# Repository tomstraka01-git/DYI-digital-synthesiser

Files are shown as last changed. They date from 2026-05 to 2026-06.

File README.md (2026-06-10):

# DYI digital synthesiser
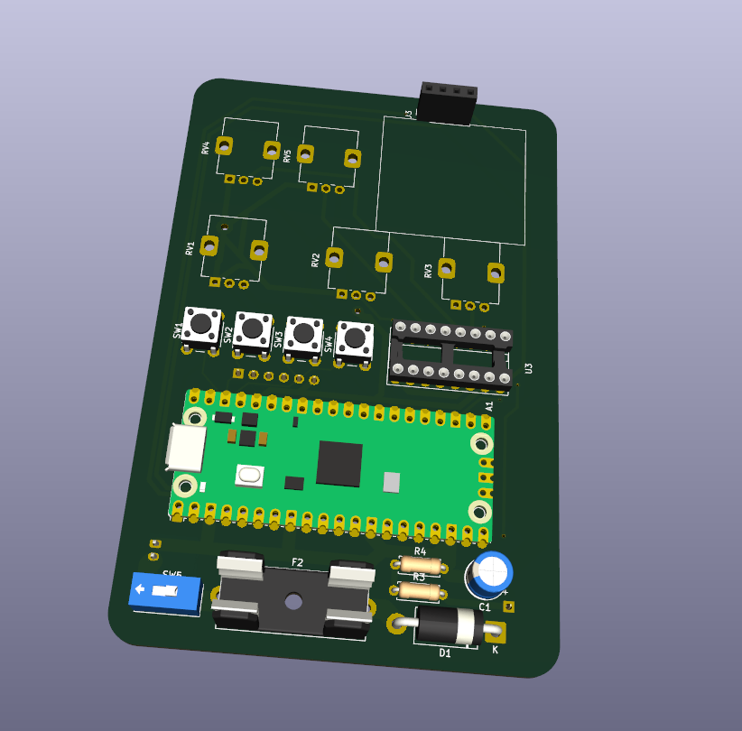
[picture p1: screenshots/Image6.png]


## What is it?
It is a digital synthesizer fully made by me. It has 4 buttons and 5 controllable analog knobs to change settings. It can produce polyphonic sound and can connect to midi. It has settings like frequency, detune, volume, filters, chorus, delay, lfo, etc. It has two 2 watt speakers to produce sound and fully made by me pcb.

## Why?
I have always liked music, since i was kid i played piano, so i wanted to connect my interest in electronics and music into one project. That is why i  made this synthesizer. It has taught me about digital sound and audio alot.

## Electronics
The project uses custom pcb and some modules. It uses PCM5102 I2S audio module for sound generation and PAM8403 for sound amplifying, before it goes into 2040 8 ohm 2 watt speakers. It uses pico 2 as a microcontroller that does all the calculations etc. The pcb is going to be made by jlcpcb and it is fully opensource. It uses voltage dividers for battery percent readings, diode and a fast fuse for safety protection.

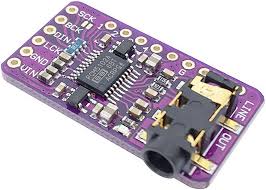
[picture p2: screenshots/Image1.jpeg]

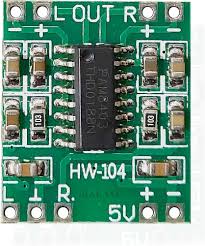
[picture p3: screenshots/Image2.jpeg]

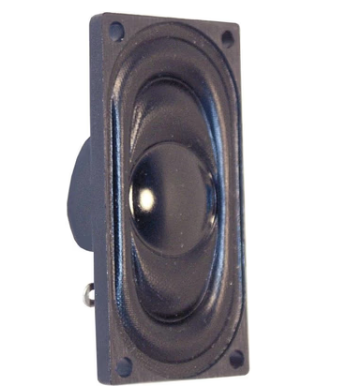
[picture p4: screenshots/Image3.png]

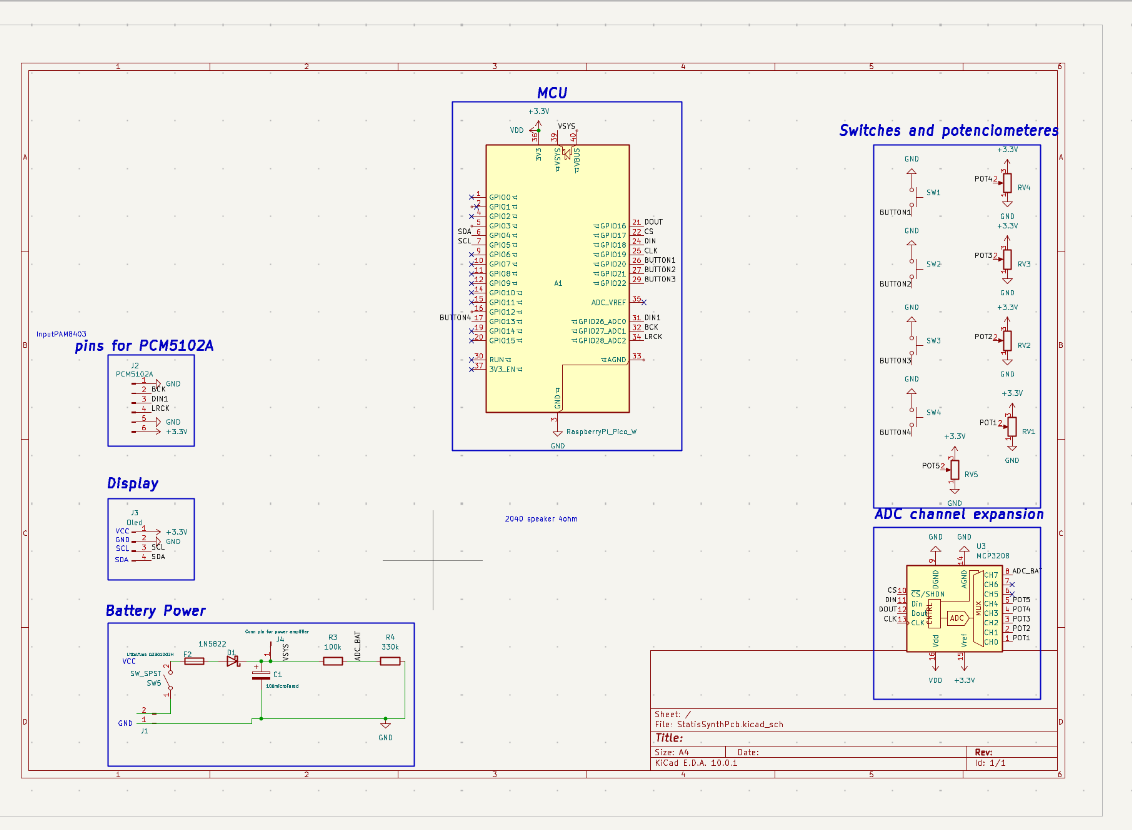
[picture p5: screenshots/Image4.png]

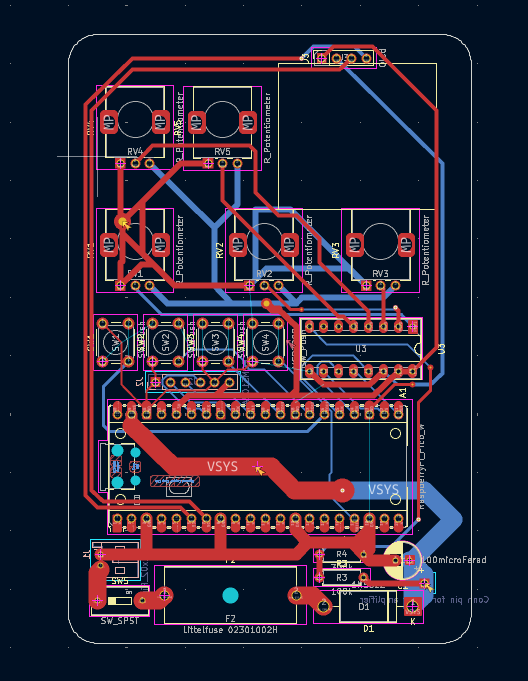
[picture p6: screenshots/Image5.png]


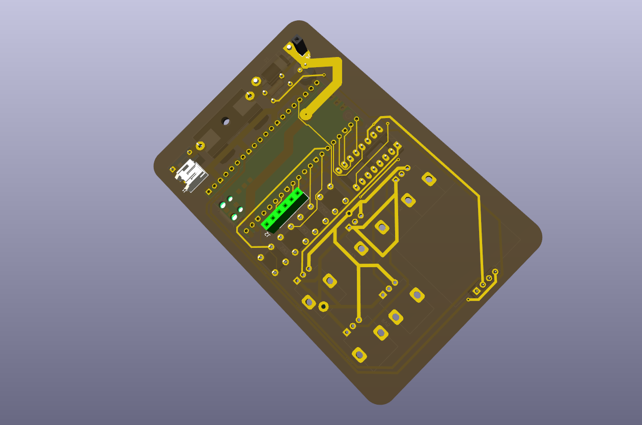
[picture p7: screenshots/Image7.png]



## Case
I wont use a case for the synthesizer, it will all be on the pcb and few things wich are not on it, like battery are gonna be held there with zip ties and other things.


| Name | Purpose | Quantity | Total Cost (USD) | Link | Distributor |
|:---|:---|---:|---:|:---|:---|
| Custom JLCPCB PCB | A custom pcb connecting parts together. | 1 | 6.9 | https://cart.jlcpcb.com/quote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 | JLCPCB |
| Raspberry Pi Pico W | Microcontroller, the brain of the synthesizer. | 1 | 11.0 | https://www.laskakit.cz/raspberry-pi-pico-w/ | laskakit.cz |
| 2040 speaker 2 watt 8 ohm | Speaker for producing audio. | 2 | 1.06 | https://www.lcsc.com/product-detail/C50387229.html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 | lcsc |
| GY-PCM5102 I2S audio module | Audio generator, wich then passes audio to the amplifier | 1 | 4.71 | https://www.laskakit.cz/gy-pcm5102-i2s-audio-modul/ | laskakit.cz |
| DuPont pins Female 40pin | Female dupont pins for pico 2. | 1 | 0.34 | https://dratek.cz/arduino-platforma/913-dupont-dutinkova-lista-samice-samec.html | Dratek.cz |
| Diode 1N5822 | Diode for reverse battery protection. 10 is minimum quantity. | 5 | 1.19 | https://www.lcsc.com/product-detail/schottky-diodes_stmicroelectronics-1n5822_C915962.html | lcsc |
| Button, 6 x 6 x 6 mm | Button for changing things in menu. | 4 | 0.39 | https://dratek.cz/arduino-platforma/1253-mikrospinac-6x6x6-mm-tlacitko.html | Dratek.cz |
| 5 $\times$ 20 GLASS QUICK BLOW FUSE 3A | Fast blow fuse for safety in the pcb. | 10 | 0.59 | https://www.lcsc.com/product-detail/Glass-Fuses_3A-250VAC_C3118.html | lcsc |
| 5 $\times$ 20mm fuse holder, PCB THT | Fuse holder. Holds the fuse, 20 is the minimum quantity. | 5 | 0.4 | https://www.lcsc.com/product-detail/C3131.html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 | lcsc |
| Metalized rezistor 100K - 0,25W 1% | Resistor for voltage divider. | 2 | 0.1 | https://dratek.cz/arduino-platforma/7653-rezistor-100k-0.25-w-1.html | Dratek.cz |
| Metalized rezistor 330K - 0,25W 1% | Resistor for voltage divider. | 4 | 0.19 | https://dratek.cz/arduino-platforma/174965-metalizovany-rezistor-330k-0-25w-1.html | Dratek.cz |
| Condensator  50v 100microfarad | Condensator for power smoothing. | 4 | 0.19 | https://dratek.cz/arduino-platforma/7825-kondenzator-100uf-50v.html | Dratek.cz |
| POT 10k$\Omega$ Through Hole | Potenciometer for the knobs in the synthesizer. Used to control value and settings. | 10 | 6.92 | https://www.lcsc.com/product-detail/C209779.html?s_z=n_q_C209779&globalKeyword=C209779 | lcsc |
| JST S2B-PH-K-S | The jst pin for battery. 20 is the minimum quantity | 20 | 0.76 | https://www.lcsc.com/product-detail/Wire-To-Board-Wire-To-Wire-Connector_JST-S2B-PH-K-S-LF-SN_C173752.html | lcsc |
| MICROCHIP MCP3208-CI/P | analog multiplexer to read potencimeters, because pico does not have enough adc pins | 1 | 4.27 | https://www.lcsc.com/product-detail/C1543277.html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 | lcsc |
| 2.54mm 16P DIP Tin Square Hole 7.62mm DIP-16 IC Sockets RoHS | Holder for the MCP3208 chip. 10 is the minimum quantity on lcsc. | 10 | 0.48 | https://www.lcsc.com/product-detail/IC-Sockets_BOOMELE-Boom-Precision-Elec-C2326_C2326.html | lcsc |
| Digital audio amplifier PAM8403 - 2 x 3W | To amplify the sound generated by the PCM5102A for speakers | 1 | 0.67 | https://dratek.cz/arduino-platforma/953-audio-zesilovac-2x3w.html | Dratek.cz |
| IIC I2C OLED displej 1,3" - White, 128 x 64 | Oled display for vizualization of the sound and values. Allows the user to see what vaues he is setting and what mode is he on. | 1 | 8.01 | https://dratek.cz/arduino-platforma/3181-iic-i2c-oled-1-3-displej-128x64-bily.html | Dratek.cz |

Total shipping: $34

Total price: $86

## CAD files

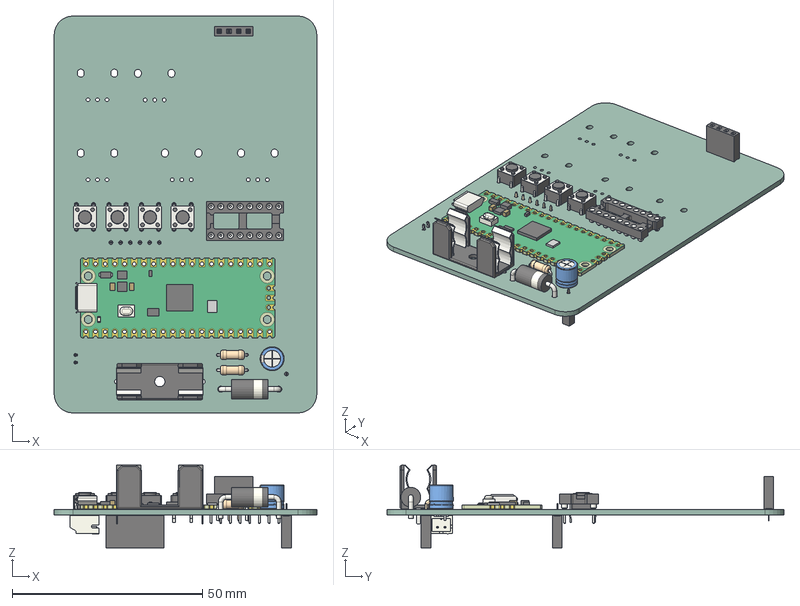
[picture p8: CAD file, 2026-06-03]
Synthesizer.step
69.0 x 104.2 x 21.7 mm
PinSocket_1x04_P2.54mm_Vertical
DIP-16_W7.62mm_Socket
CP_Radial_D6.3mm_P2.50mm
SW_PUSH_6mm x 4
R_Axial_DIN0207_L6.3mm_D2.5mm_P7.62mm_Horizontal x 2
RaspberryPi_Pico
D_DO-201AD_P15.24mm_Horizontal
Fuseholder_Cylinder-5x20mm_Schurter_0031_8201_Horizontal_Open
PinSocket_1x01_P2.54mm_Vertical
JST_PH_S2B-PH-K_1x02_P2.00mm_Horizontal
PinSocket_1x06_P2.54mm_Vertical
StatisSynthPcb_PCB

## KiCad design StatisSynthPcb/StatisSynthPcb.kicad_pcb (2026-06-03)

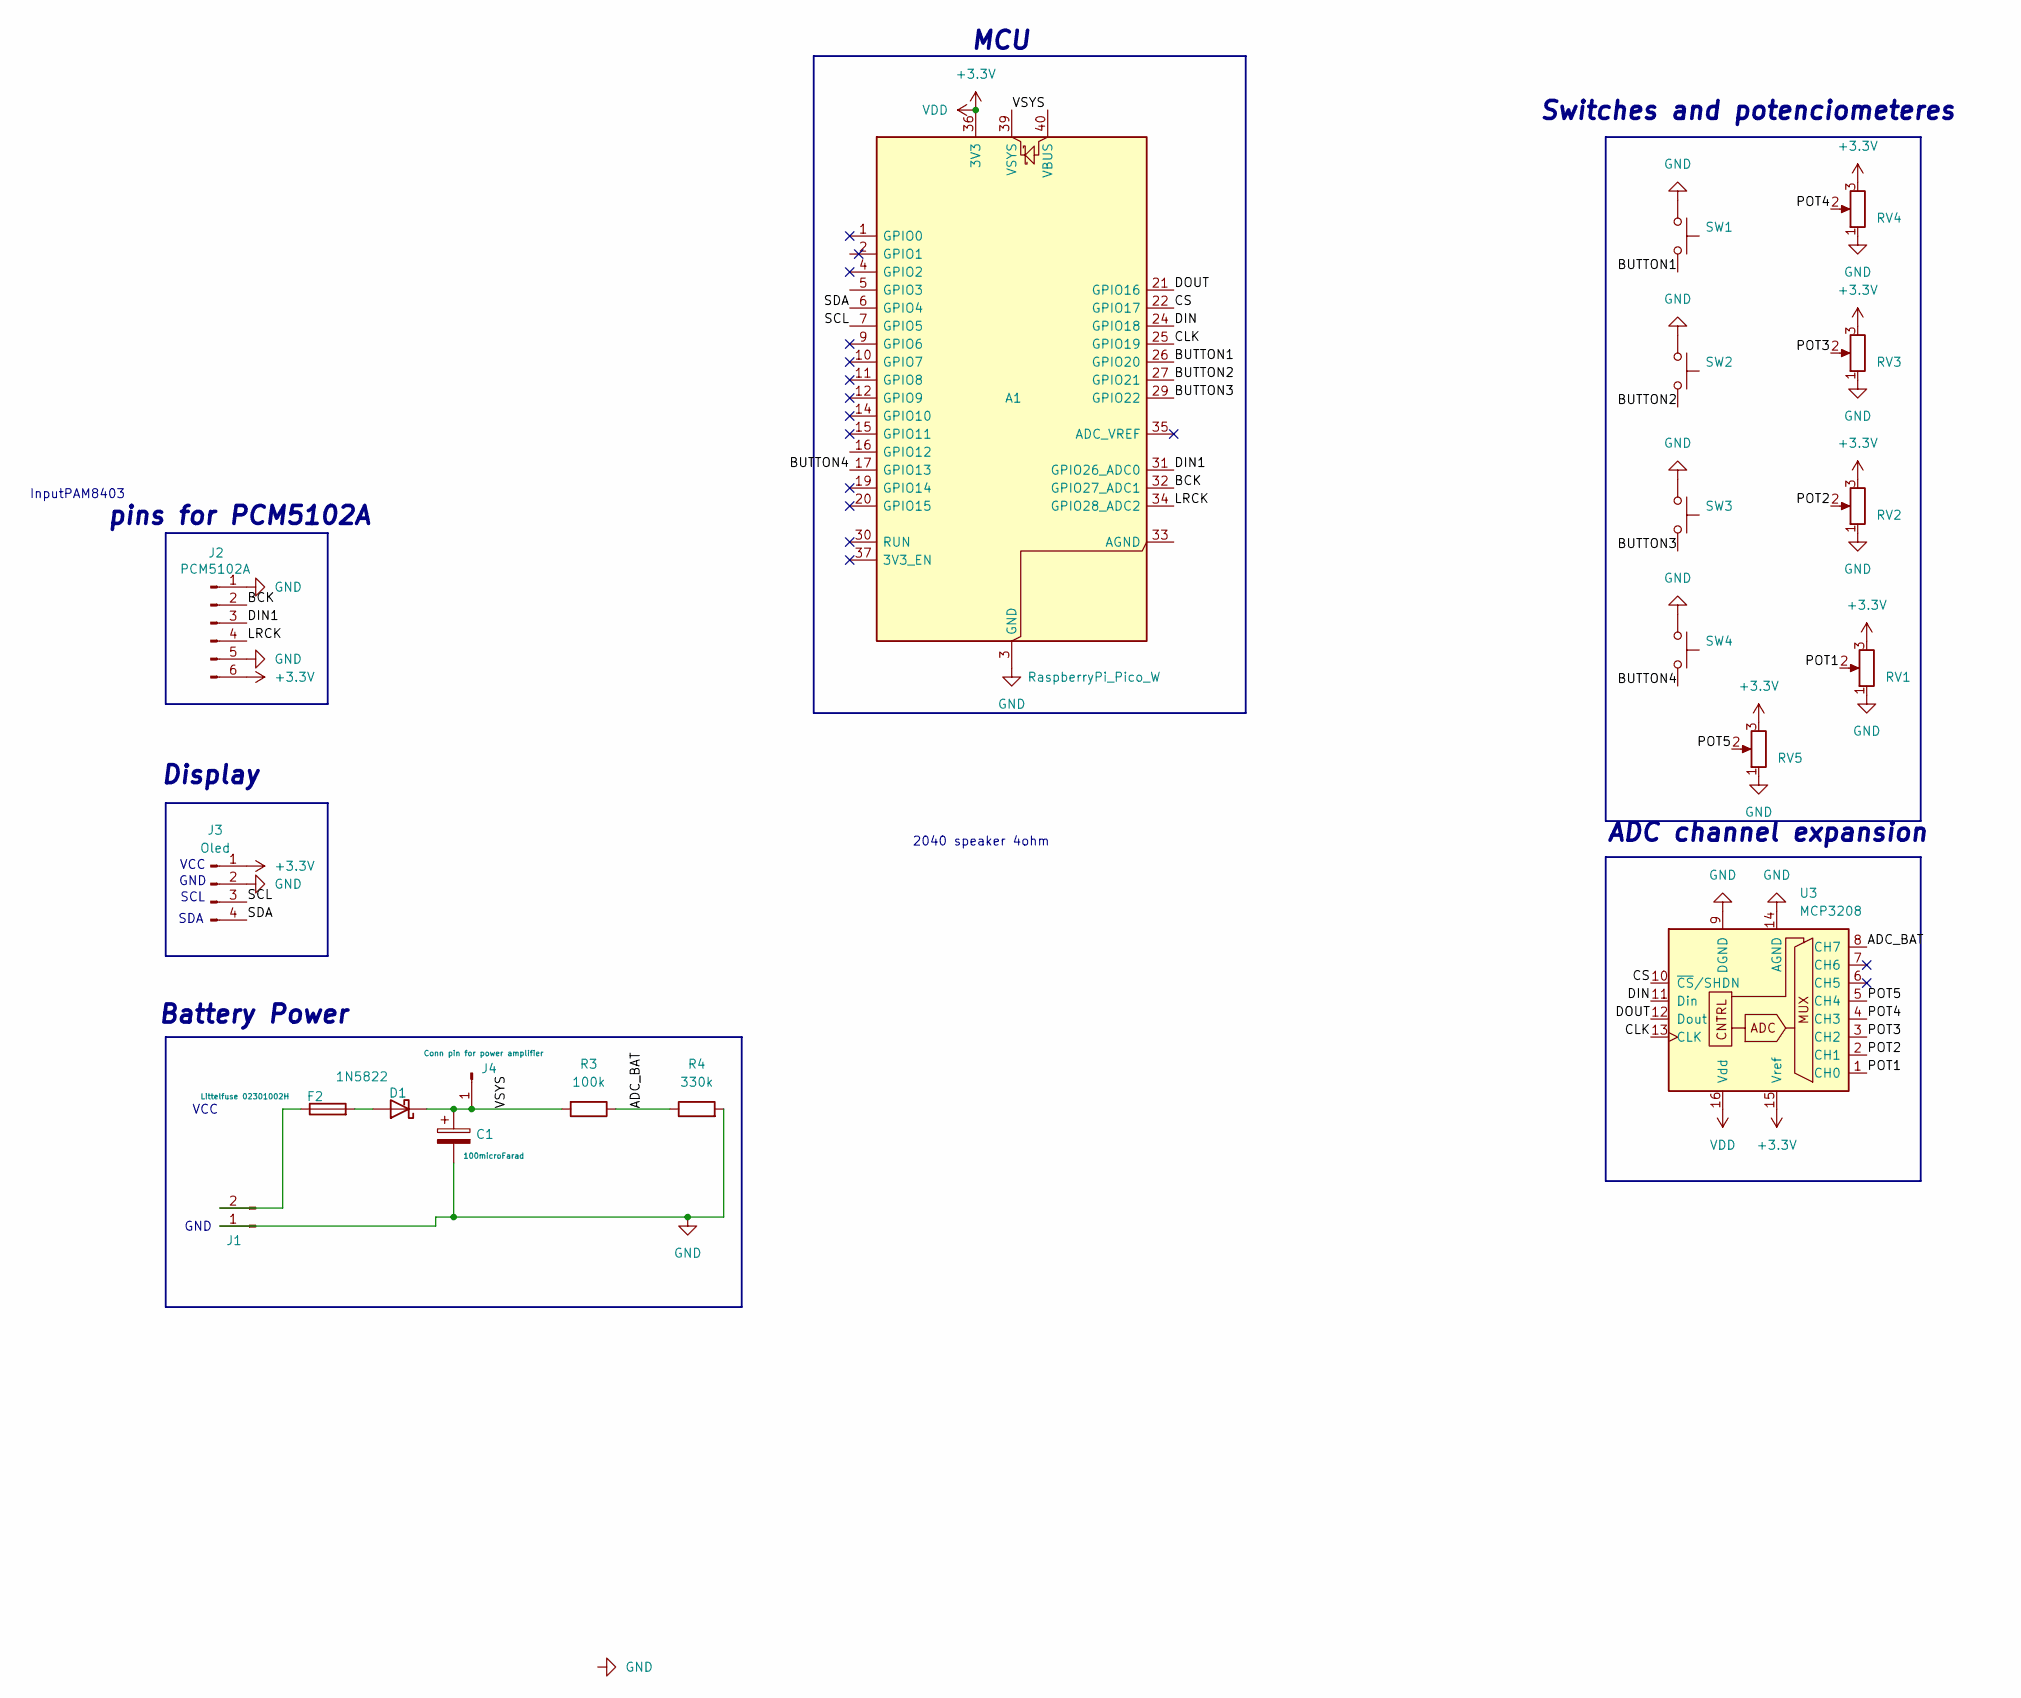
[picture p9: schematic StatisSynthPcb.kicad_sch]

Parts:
A1: RaspberryPi_Pico_W; RaspberryPi_Pico_Common
C1: 100microFarad; CP_Radial_D6.3mm_P2.50mm
D1: 1N5822; D_DO-201AD_P15.24mm_Horizontal
F2: Littelfuse 02301002H; Fuseholder_Cylinder-5x20mm_Schurter_0031_8201_Horizontal_Op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
J1: Conn_01x02_Pin; JST_PH_S2B-PH-K_1x02_P2.00mm_Horizontal
J2: PCM5102A; PinSocket_1x06_P2.54mm_Vertical
J3: Oled; PinSocket_1x04_P2.54mm_Vertical
J4: Conn pin for power amplifier; PinSocket_1x01_P2.54mm_Vertical
R3: 100k; R_Axial_DIN0207_L6.3mm_D2.5mm_P7.62mm_Horizontal
R4: 330k; R_Axial_DIN0207_L6.3mm_D2.5mm_P7.62mm_Horizontal
RV1, RV2, RV3, RV4, RV5: R_Potentiometer; Potentiometer_Alps_RK09K_Single_Vertical
SW1, SW2, SW3, SW4: SW_Push; SW_PUSH_6mm
U3: MCP3208; DIP-16_W7.62mm_Socket_LongPads

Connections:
+3.3V: A1.36 (3V3), J2.6, J3.1, RV1.3, RV2.3, RV3.3, RV4.3, RV5.3, U3.15 (Vref), U3.16 (Vdd)
/ADC_BAT: R3.1, R4.1, U3.8 (CH7)
/BCK: A1.32 (GPIO27_ADC1), J2.2
/BUTTON1: A1.26 (GPIO20), SW1.2
/BUTTON2: A1.27 (GPIO21), SW2.2
/BUTTON3: A1.29 (GPIO22), SW3.2
/BUTTON4: A1.17 (GPIO13), SW4.2
/CLK: A1.25 (GPIO19), U3.13 (CLK)
/CS: A1.22 (GPIO17), U3.10 (~CS/SHDN)
/DIN: A1.24 (GPIO18), U3.11 (Din)
/DIN1: A1.31 (GPIO26_ADC0), J2.3
/DOUT: A1.21 (GPIO16), U3.12 (Dout)
/LRCK: A1.34 (GPIO28_ADC2), J2.4
/POT1: RV1.2, U3.1 (CH0)
/POT2: RV2.2, U3.2 (CH1)
/POT3: RV3.2, U3.3 (CH2)
/POT4: RV4.2, U3.4 (CH3)
/POT5: RV5.2, U3.5 (CH4)
/SCL: A1.7 (GPIO5), J3.3
/SDA: A1.6 (GPIO4), J3.4
/VSYS: A1.39 (VSYS), C1.1, D1.1 (K), J4.1 (Pin_1_1), R3.2
GND: A1.3 (GND), A1.8 (GND), A1.13 (GND), A1.18 (GND), A1.23 (GND), A1.28 (GND), A1.38 (GND), C1.2, J1.1, J2.1, J2.5, J3.2, R4.2, RV1.1, RV2.1, RV3.1, RV4.1, RV5.1, SW1.1, SW2.1, SW3.1, SW4.1, U3.9 (DGND), U3.14 (AGND)
unnamed: D1.2 (A), F2.2
unnamed: F2.1, J1.2

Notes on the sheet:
Battery Power
ADC channel expansion
SCL
VCC
InputPAM8403
GND
pins for PCM5102A
SDA
Switches and potenciometeres
GND
Display
2040 speaker 4ohm
MCU

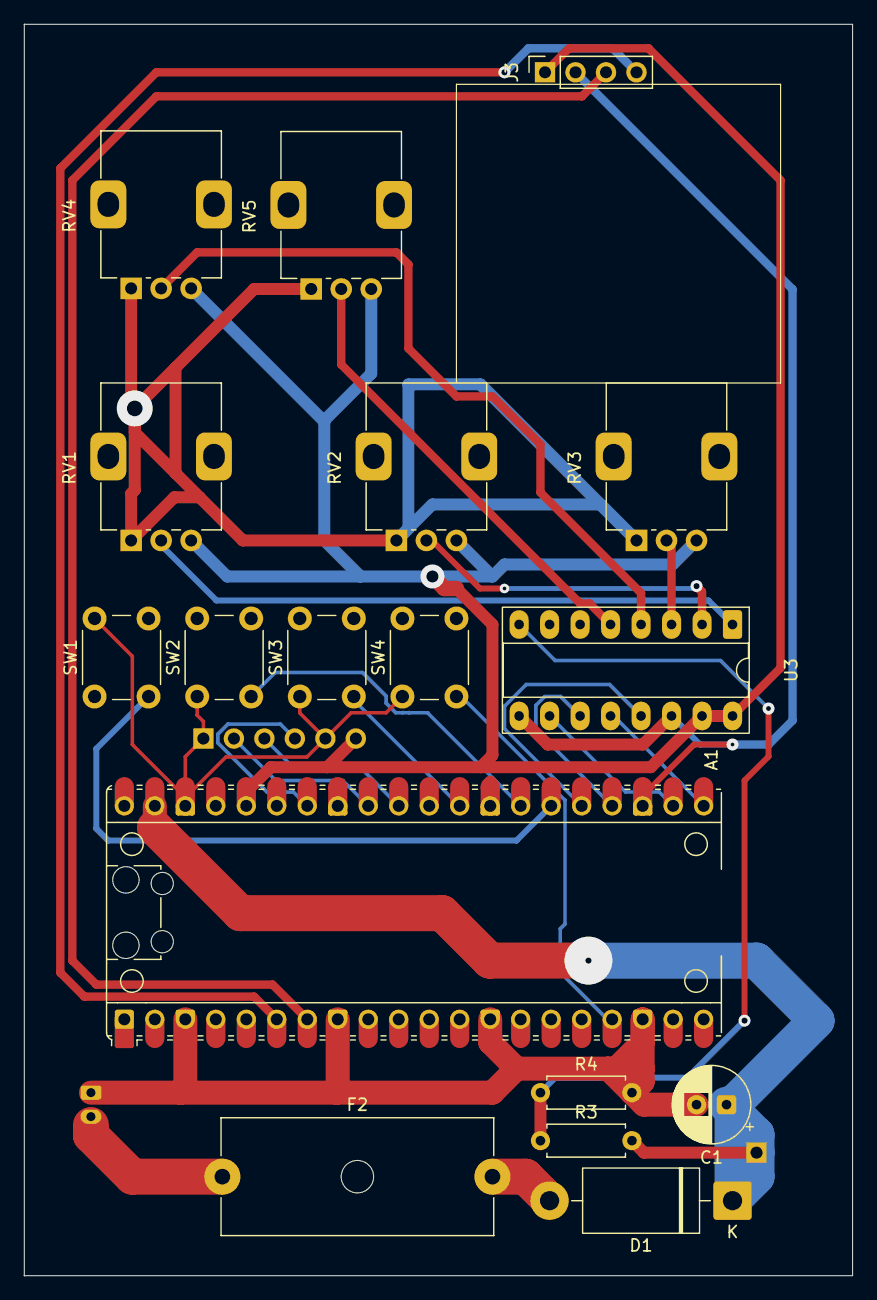
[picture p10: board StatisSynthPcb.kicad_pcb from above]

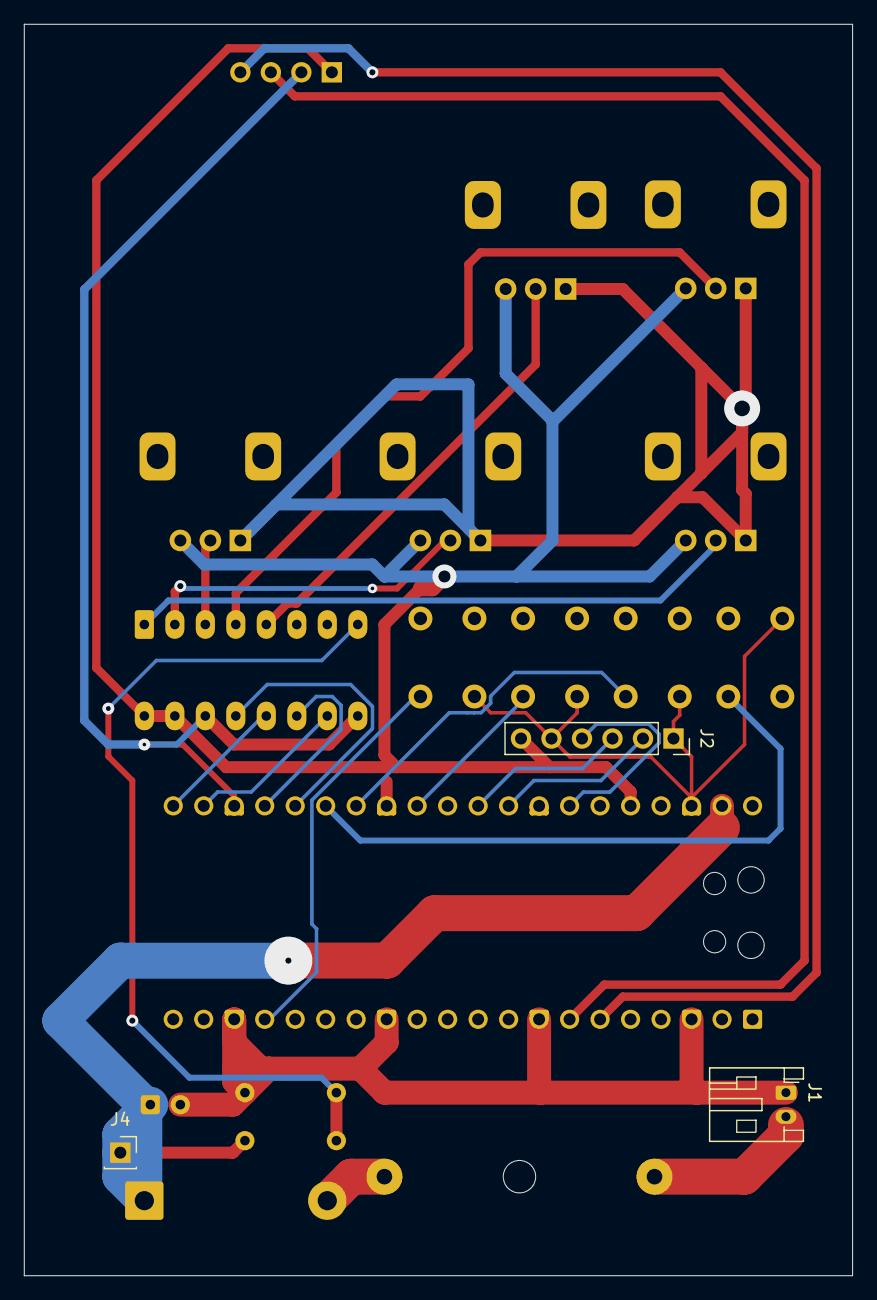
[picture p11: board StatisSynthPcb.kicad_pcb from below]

Board: 2 copper layers, 69.0 x 104.2 mm, 20 parts (3 on the bottom side), 24 nets.

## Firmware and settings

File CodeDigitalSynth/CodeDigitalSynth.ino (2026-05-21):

#include <I2S.h>
#include <SPI.h>
#include "MCP_ADC.h"
#include <Adafruit_TinyUSB.h>
#include <MIDI.h>
#include "pico/multicore.h"

#include <Adafruit_GFX.h>
#include <Adafruit_SSD1306.h>
#include <Wire.h>

#include "hardware/sync.h"

#define LRCK_PIN  28   
#define BCK_PIN   27   
#define DIN_PIN   26   

#define SAMPLE_RATE 44100
#define AMPLITUDE   32767

#define MCP_DOUT  16   
#define MCP_CS    17   
#define MCP_DIN   18   
#define MCP_CLK   19

#define BUTTON1 20 // OSC1 waveform cycle
#define BUTTON2 21 // Sound ON/OFF
#define BUTTON3 22 // Mode cycle
#define BUTTON4 13 // OSC2 waveform cycle  ← now used


#define SCREEN_WIDTH 128
#define SCREEN_HEIGHT 64
#define OLED_RESET -1


Adafruit_SSD1306 display(SCREEN_WIDTH, SCREEN_HEIGHT, &Wire, OLED_RESET);


Adafruit_USBD_MIDI usb_midi;
MIDI_CREATE_INSTANCE(Adafruit_USBD_MIDI, usb_midi, MIDI);

// Chorus variables
#define CHORUS_SAMPLES 2000
int16_t chorusBuffer[CHORUS_SAMPLES];

float chorus_rate = 0.0f;
float chorus_depth = 0.0f;
int chorusWritePos = 0;
float chorusMix = 0.0f;


enum ADSRState { ATTACK, DECAY, SUSTAIN, RELEASE, OFF };
ADSRState envState = OFF;

#define WAVE_SAMPLES 128
volatile int16_t waveBuffer[WAVE_SAMPLES];
volatile int waveIndex = 0;

// Polyphony
#define MAX_VOICES 4

struct Voice {
  float phase1, phase2;
  float currentFreq, targetFreq;
  float envLevel;
  ADSRState envState;
  int midiNote;
  bool active;
};

Voice voices[MAX_VOICES];


struct SVF { float low, band; };
SVF svf[MAX_VOICES] = {};

// Main mode variables
float volume = 1.0f;
float detune = 0.0f;
float portamento = 0.0f;
float osc2Level = 0.5f;  // 0 = OSC1 only, 1 = OSC2 only, 0.5 = equal
float osc2SemiOffset = 0.0f;  // -24 to +24 semitones

float baseFrequency = 440.0f;  
int   midiNote = 69; 

float currentFrequency = 440.0f;
float targetFrequency = 440.0f; 

// FX mode variables
float cutoff = 1000.0f;
float resonance = 0.0f;
float delayTime = 0.0f;
float delayMix  = 0.0f;

#define DELAY_MAX_SAMPLES (SAMPLE_RATE)
int16_t delayBuffer[DELAY_MAX_SAMPLES] = {0};
int delayWritePos = 0;

// LFO mode variables
float lfoEnvelope = 0.0f;
float lfoRate = 1.0f;
float lfoDepth = 0.0f;
float lfoTarget = 0;
float lfoAttack = 0.5f;

enum Mode { MAIN, ADSR, FX, FX2, LFO };
Mode currentMode = MAIN;

int waveform1 = 0;
int waveform2 = 1;

I2S i2s(OUTPUT);
MCP3208 mcp(&SPI); 



float attackRate = 0.015f;
float decayRate = 0.003f;
float sustainLevel = 0.6f;
float releaseRate = 0.003f;
float envLevel = 0.0f;

int allocateVoice(int note) {
  // First: reuse same note if already playing
  for (int i = 0; i < MAX_VOICES; i++)
    if (voices[i].midiNote == note && voices[i].envState != OFF)
      return i;

  // Second: find a silent voice
  for (int i = 0; i < MAX_VOICES; i++)
    if (voices[i].envState == OFF) return i;

  // Third: steal the voice with lowest envelope level
  int steal = 0;
  for (int i = 1; i < MAX_VOICES; i++)
    if (voices[i].envLevel < voices[steal].envLevel) steal = i;
  return steal;
}

void voiceNoteOn(int note) {
  float freq = baseFrequency * powf(2.0f, (note - 69.0f) / 12.0f);
  int v = allocateVoice(note);
  voices[v].midiNote   = note;
  voices[v].targetFreq = freq;
  if (voices[v].envState == OFF)
    voices[v].currentFreq = freq;  // snap freq if voice was silent
  voices[v].envState = ATTACK;
  voices[v].envLevel = 0.0f;
  voices[v].active   = true;
  lfoEnvelope = 0.0f;
}

void voiceNoteOff(int note) {
  for (int i = 0; i < MAX_VOICES; i++)
    if (voices[i].midiNote == note &&
        voices[i].envState != OFF &&
        voices[i].envState != RELEASE)
      voices[i].envState = RELEASE;
}

float analogReadLog(uint8_t ch, float minT, float maxT) {
  float pot = mcp.read(ch) / 4095.0f;
  return minT * powf(maxT / minT, pot);
}

void updateButtons() {
  static bool last1 = HIGH, last2 = HIGH, last3 = HIGH, last4 = HIGH;
  static unsigned long lastTime1 = 0, lastTime3 = 0, lastTime4 = 0;

  bool b1 = digitalRead(BUTTON1);
  bool b2 = digitalRead(BUTTON2);
  bool b3 = digitalRead(BUTTON3);
  bool b4 = digitalRead(BUTTON4);

  // OSC1 waveform cycle
  if (last1 == HIGH && b1 == LOW && millis() - lastTime1 > 50) {
    waveform1 = (waveform1 + 1) % 4;
    lastTime1 = millis();
  }

  // note on/off
  if (last2 == HIGH && b2 == LOW)  voiceNoteOn(69);
  if (last2 == LOW  && b2 == HIGH) voiceNoteOff(69);

  // mode cycle
  if (last3 == HIGH && b3 == LOW && millis() - lastTime3 > 50) {
    currentMode = (Mode)((currentMode + 1) % 5);
    lastTime3 = millis();
  }

  // OSC2 waveform cycle  
  if (last4 == HIGH && b4 == LOW && millis() - lastTime4 > 50) {
    waveform2 = (waveform2 + 1) % 4;
    lastTime4 = millis();
  }

  last1 = b1; last2 = b2; last3 = b3; last4 = b4;
}

void updateKnobs() {
  switch (currentMode) {
    case MAIN:
      volume = mcp.read(0) / 4095.0f;
    {
    float detuneAmount = (mcp.read(1) / 2047.5f) - 1.0f;
    
  
    float a4Freq = 300.0f + (mcp.read(2) / 4095.0f) * 180.0f;
    baseFrequency = a4Freq;  // baseFrequency now means "what is A4"

    detune = a4Freq * (powf(2.0f, detuneAmount * 50.0f / 1200.0f) - 1.0f);
  }
    portamento = mcp.read(3) / 4095.0f; 
    if (mcp.read(3) < 10) portamento = 0.0f;
    osc2SemiOffset = (mcp.read(4) / 4095.0f) * 48.0f - 24.0f;  // -24 to +24 semitones
    break;

    case ADSR:
      attackRate = 1.0f / (analogReadLog(0, 0.001f, 3.0f)  * SAMPLE_RATE);
      decayRate = 1.0f / (analogReadLog(1, 0.005f, 2.0f)  * SAMPLE_RATE);
      sustainLevel = mcp.read(2) / 4095.0f;
      releaseRate = 1.0f / (analogReadLog(3, 0.005f, 5.0f)  * SAMPLE_RATE);
      break;

    case FX:
      cutoff    = analogReadLog(0, 200.0f, 8000.0f);
      resonance = mcp.read(1) / 4095.0f;
      delayTime = mcp.read(2) / 4095.0f;
      delayMix  = mcp.read(3) / 4095.0f;
      break;

    case FX2:
      chorus_rate  = mcp.read(0) / 4095.0f * 3.0f;
      chorus_depth = mcp.read(1) / 4095.0f * 20.0f;
      chorusMix    = mcp.read(2) / 4095.0f;
      break;

    case LFO:

      lfoRate = analogReadLog(0, 0.1f, 20.0f);
      lfoDepth = mcp.read(1) / 4095.0f;
      lfoTarget = (float)(mcp.read(2) * 3 / 4096);
      lfoAttack = analogReadLog(3, 0.05f, 5.0f);   
      osc2Level = mcp.read(4) / 4095.0f;          
      break;
  }
}

void readMidi() {
  if (MIDI.read()) {
    byte type = MIDI.getType();
    byte note = MIDI.getData1();
    byte vel  = MIDI.getData2();

    if (type == midi::NoteOn && vel > 0) {
      voiceNoteOn(note);
    } else if (type == midi::NoteOff ||
              (type == midi::NoteOn && vel == 0)) {
      voiceNoteOff(note);
    }
  }
}

int16_t applyFilter(int v, int16_t input, float fc) {
  float f = 2.0f * sinf(M_PI * fc / SAMPLE_RATE);
  if (f > 0.95f) f = 0.95f;
  float q  = 2.0f - (resonance * 1.9f);
  float in = (float)input;
  svf[v].low  += f * svf[v].band;
  float high   = in - svf[v].low - q * svf[v].band;
  svf[v].band  = f * high + svf[v].band;
  return (int16_t)constrain((int32_t)svf[v].low, -32768, 32767);
}

float applyLFO() {
  static float lfoPhase = 0.0f;

  float ar = 1.0f / (lfoAttack * SAMPLE_RATE);
  lfoEnvelope += ar;
  if (lfoEnvelope > 1.0f) lfoEnvelope = 1.0f;

  float lfoWave = sinf(lfoPhase);

  lfoPhase += 2.0f * M_PI * lfoRate / SAMPLE_RATE;
  if (lfoPhase >= 2.0f * M_PI) lfoPhase -= 2.0f * M_PI;

  return lfoWave * lfoDepth * lfoEnvelope;
}


inline int16_t generateSample(int wf, float ph) {
  switch (wf) {
    case 0: return (int16_t)(sinf(ph) * AMPLITUDE);
    case 1: return (int16_t)((ph < M_PI ? 1.0f : -1.0f) * AMPLITUDE);
    case 2: return (int16_t)((1.0f - ph / M_PI) * AMPLITUDE);
    case 3: return (int16_t)((ph < M_PI
              ? (ph / M_PI * 2.0f - 1.0f)
              : (3.0f - ph / M_PI * 2.0f)) * AMPLITUDE);
    default: return 0;
  }
}

const char* waveName(int wf) {
  switch(wf) {
    case 0: return "SIN";
    case 1: return "SQR";
    case 2: return "SAW";
    case 3: return "TRI";
    default: return "???";
  }
}

const char* modeName(Mode m) {
  switch(m) {
    case MAIN: return "MAIN";
    case ADSR: return "ADSR";
    case FX:   return "FX1 ";
    case FX2:  return "FX2 ";
    case LFO:  return "LFO ";
    default:   return "????";
  }
}

void updateOled(int16_t sample) {
  display.clearDisplay();

  // Waveform part (top 18px) 
  int16_t localBuf[WAVE_SAMPLES];
  uint32_t savedIdx;

  
  uint32_t irq = save_and_disable_interrupts();
  memcpy((void*)localBuf, (void*)waveBuffer, sizeof(localBuf));
  savedIdx = waveIndex;
  restore_interrupts(irq);

  for (int x = 0; x < 128; x++) {
    int idx = (savedIdx + x) % WAVE_SAMPLES;
    int y = map((int)localBuf[idx], -32768, 32767, 17, 0);
    display.drawPixel(x, y, SSD1306_WHITE);
  }

  // Divider line 
  display.drawFastHLine(0, 19, 128, SSD1306_WHITE);

  // Mode indicator (top right) 
  display.setTextSize(1);
  display.setTextColor(SSD1306_WHITE);
  display.setCursor(98, 21);
  display.print(modeName(currentMode));

  
  switch (currentMode) {

    case MAIN:

      display.setCursor(0, 21);
      display.print("O1:"); display.print(waveName(waveform1));
      display.print(" O2:"); display.print(waveName(waveform2));

      display.setCursor(0, 31);
      display.print("A4:"); display.print((int)baseFrequency); display.print("Hz"); // changed Fr: to A4:

      display.setCursor(0, 41);
      display.print("Vl:"); display.print((int)(volume * 100)); display.print("%");
      display.print(" Dt:"); display.print((int)(detune * 10) / 10.0f);

      display.setCursor(0, 51);
      display.print("PT:"); display.print((int)(portamento * 100)); display.print("%");
      display.print(" O2:"); display.print((int)(osc2SemiOffset)); display.print("st");
      break;

    case ADSR: {
      // Draw ADSR shape (right side, 50px wide)
      // A
      display.drawLine(78, 62, 88, 22, SSD1306_WHITE);
      // D
      int dY = 22 + (int)((1.0f - sustainLevel) * 25);
      display.drawLine(88, 22, 98, dY, SSD1306_WHITE);
      // S
      display.drawLine(98, dY, 108, dY, SSD1306_WHITE);
      // R
      display.drawLine(108, dY, 118, 62, SSD1306_WHITE);

      // Text values (left side)
      display.setCursor(0, 21);
      display.print("A:"); 
      display.print(1.0f / (attackRate * SAMPLE_RATE), 2);
      display.print("s");

      display.setCursor(0, 31);
      display.print("D:");
      display.print(1.0f / (decayRate  * SAMPLE_RATE), 2);
      display.print("s");

      display.setCursor(0, 41);
      display.print("S:");
      display.print((int)(sustainLevel * 100));
      display.print("%");

      display.setCursor(0, 51);
      display.print("R:");
      display.print(1.0f / (releaseRate * SAMPLE_RATE), 2);
      display.print("s");
      break;
    }

    case FX:
      display.setCursor(0, 21);
      display.print("Cut:"); display.print((int)cutoff); display.print("Hz");

      display.setCursor(0, 31);
      display.print("Res:"); display.print((int)(resonance * 100)); display.print("%");

      display.setCursor(0, 41);
      display.print("Dly:"); display.print((int)(delayTime * 1000)); display.print("ms");
      display.print(" Mx:"); display.print((int)(delayMix * 100)); display.print("%");

      display.setCursor(0, 51);
      display.print("Chr:"); display.print(chorus_rate, 1); display.print("Hz");
      display.print(" Mx:"); display.print((int)(chorusMix * 100)); display.print("%");
      break;
    
    case FX2:
      display.setCursor(0, 21);
      display.print("CRt:"); display.print(chorus_rate, 1); display.print("Hz");

      display.setCursor(0, 31);
      display.print("CDp:"); display.print((int)chorus_depth); display.print("ms");

      display.setCursor(0, 41);
      display.print("CMx:"); display.print((int)(chorusMix * 100)); display.print("%");
      break;
      
    case LFO: {
      const char* targets[] = { "PITCH", "VOL  ", "FILT " };
      display.setCursor(0, 21);
      display.print("Rt:"); display.print(lfoRate, 1); display.print("Hz");

      display.setCursor(0, 31);
      display.print("Dp:"); display.print((int)(lfoDepth * 100)); display.print("%");

      display.setCursor(0, 41);
      display.print("Tg:"); display.print(targets[(int)lfoTarget]);

      display.setCursor(0, 51);
      display.print("Atk:"); display.print(lfoAttack, 1); display.print("s");
      break;
    }
  }

  // MIDI note + env state (bottom right) 

  ADSRState displayState = OFF;
  for (int i = 0; i < MAX_VOICES; i++)
    if (voices[i].envState != OFF) { displayState = voices[i].envState; break; }

  const char* envNames[] = { "ATK","DEC","SUS","REL","OFF" };
  display.setCursor(98, 51);
  display.print(envNames[displayState]);

  display.display();
}

void controlLoop() {
  while (true) {
    updateButtons();
    updateKnobs();
    updateOled(0);
    delay(50);
  }
}

void setup() {
  USBDevice.begin();

  pinMode(BUTTON1, INPUT_PULLUP);
  pinMode(BUTTON2, INPUT_PULLUP);
  pinMode(BUTTON3, INPUT_PULLUP);
  pinMode(BUTTON4, INPUT_PULLUP);

  SPI.setRX(MCP_DOUT);
  SPI.setTX(MCP_DIN);
  SPI.setSCK(MCP_CLK);
  SPI.begin();
  mcp.begin(MCP_CS);
  
  i2s.setBCLK(BCK_PIN);   
  i2s.setDATA(DIN_PIN);  
  i2s.setLRCLK(LRCK_PIN);
  i2s.setBitsPerSample(16);
  i2s.begin(SAMPLE_RATE);

  usb_midi.begin();
  MIDI.begin(MIDI_CHANNEL_OMNI);

  
  Wire.setSDA(4);  // GP4
  Wire.setSCL(5);  // GP5
  Wire.begin();

  display.begin(SSD1306_SWITCHCAPVCC, 0x3C); 
  display.clearDisplay();

  multicore_launch_core1(controlLoop);
}


void loop() {
  readMidi();

  float lfoValue  = applyLFO();
  float cutoffMod = cutoff;
  if ((int)lfoTarget == 2) {
    cutoffMod *= (1.0f + lfoValue);
    cutoffMod  = constrain(cutoffMod, 20.0f, 20000.0f);
  }

  float portaCoeff = 1.0f - portamento * 0.9997f;
  int32_t mixedOut = 0;

  for (int v = 0; v < MAX_VOICES; v++) {
    Voice& vx = voices[v];
    if (vx.envState == OFF) continue;

    // Portamento
    vx.currentFreq += (vx.targetFreq - vx.currentFreq) * portaCoeff;

    // ADSR
    switch (vx.envState) {
      case ATTACK:
        vx.envLevel += attackRate;
        if (vx.envLevel >= 1.0f) { vx.envLevel = 1.0f; vx.envState = DECAY; }
        break;
      case DECAY:
        vx.envLevel -= decayRate;
        if (vx.envLevel <= sustainLevel) { vx.envLevel = sustainLevel; vx.envState = SUSTAIN; }
        break;
      case SUSTAIN:
        vx.envLevel = sustainLevel;
        break;
      case RELEASE:
        vx.envLevel -= releaseRate;
        if (vx.envLevel <= 0.0f) {
          vx.envLevel = 0.0f;
          vx.envState = OFF;
          vx.active   = false;
          continue;
        }
        break;
      default: break;
    }

    // Frequency + LFO pitch mod
    float freqMod = vx.currentFreq;
    if ((int)lfoTarget == 0)
      freqMod += vx.currentFreq * lfoValue * 0.05f;

    float inc1 = 2.0f * M_PI * (freqMod + detune) / SAMPLE_RATE;
    float osc2Freq = freqMod * powf(2.0f, osc2SemiOffset / 12.0f);
    float inc2 = 2.0f * M_PI * osc2Freq / SAMPLE_RATE;

    // Oscillators
    int16_t s1 = generateSample(waveform1, vx.phase1);
    int16_t s2 = generateSample(waveform2, vx.phase2);
    int32_t osc = (int32_t)(s1 * (1.0f - osc2Level))
                + (int32_t)(s2 * osc2Level);

    // Envelope + volume
    int32_t s = (int32_t)(osc * vx.envLevel * volume);

    // Volume LFO
    if ((int)lfoTarget == 1)
      s = (int32_t)(s * (1.0f + lfoValue * 0.5f));

    s = constrain(s, -32768, 32767);

    // Per-voice filter
    int16_t filtered = applyFilter(v, (int16_t)s, cutoffMod);

    // Mix (divide by MAX_VOICES to prevent clipping)
    mixedOut += filtered / MAX_VOICES;

    // Advance phases
    vx.phase1 += inc1;
    if (vx.phase1 >= 2.0f * M_PI) vx.phase1 -= 2.0f * M_PI;
    vx.phase2 += inc2;
    if (vx.phase2 >= 2.0f * M_PI) vx.phase2 -= 2.0f * M_PI;
  }

  // Delay
  mixedOut = constrain(mixedOut, -32768, 32767);
  int16_t preDly = (int16_t)mixedOut;

  int delaySamples = (int)(delayTime * (DELAY_MAX_SAMPLES - 1));
  int delayReadPos = delayWritePos - delaySamples;
  if (delayReadPos < 0) delayReadPos += DELAY_MAX_SAMPLES;

  int16_t delaySig = delayBuffer[delayReadPos];
  delayBuffer[delayWritePos] = preDly + (int16_t)(delaySig * 0.5f);
  delayWritePos = (delayWritePos + 1) % DELAY_MAX_SAMPLES;

  int32_t out = (int32_t)(preDly * (1.0f - delayMix))
              + (int32_t)(delaySig * delayMix);
  out = constrain(out, -32768, 32767);


// Chorus
  static float chorusLfoPhase = 0.0f;
  chorusBuffer[chorusWritePos] = (int16_t)out;

  float chorusLfo = sinf(chorusLfoPhase);
  chorusLfoPhase += 2.0f * M_PI * chorus_rate / SAMPLE_RATE;
  if (chorusLfoPhase >= 2.0f * M_PI) chorusLfoPhase -= 2.0f * M_PI;

  // Base delay ~10ms plus LFO modulation
  float delayMs = 10.0f + chorusLfo * chorus_depth;
  int chorusDelaySamples = (int)(delayMs * SAMPLE_RATE / 1000.0f);
  chorusDelaySamples = constrain(chorusDelaySamples, 1, CHORUS_SAMPLES - 1);

  int chorusReadPos = chorusWritePos - chorusDelaySamples;
  if (chorusReadPos < 0) chorusReadPos += CHORUS_SAMPLES;

  int16_t chorusSig = chorusBuffer[chorusReadPos];
  chorusWritePos = (chorusWritePos + 1) % CHORUS_SAMPLES;

  out = (int32_t)(out * (1.0f - chorusMix))
      + (int32_t)(chorusSig * chorusMix);
  out = constrain(out, -32768, 32767);

  
  waveBuffer[waveIndex % WAVE_SAMPLES] = preDly;
  waveIndex++;

  i2s.write16((int16_t)out, (int16_t)out);
}

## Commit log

2026-04-30 made first pcb version
    [StatisSynthPcb.kicad_sch]
2026-05-10 change in schematic
    [StatisSynthPcb.kicad_sch]
2026-05-14 added resonance filter
2026-05-14 added other oscillator and core
    [CodeDigitalSynth.ino]
2026-05-20 changed pcb fuse, diode etc
    [StatisSynthPcb.kicad_pcb, StatisSynthPcb.kicad_sch]
2026-05-21 chnages to code and pcb
    [StatisSynthPcb.kicad_pcb, StatisSynthPcb.kicad_sch]
2026-06-02 pcb change
    [StatisSynthPcb.kicad_pcb, StatisSynthPcb.kicad_sch]
2026-06-03 added gerbers photos bom
    [DYI digital synthesiser-bom.csv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]
2026-06-03 added step
    [Synthesizer.step]
